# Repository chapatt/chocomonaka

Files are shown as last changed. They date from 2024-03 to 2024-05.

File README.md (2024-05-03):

# choco monaka

Fighting game controller

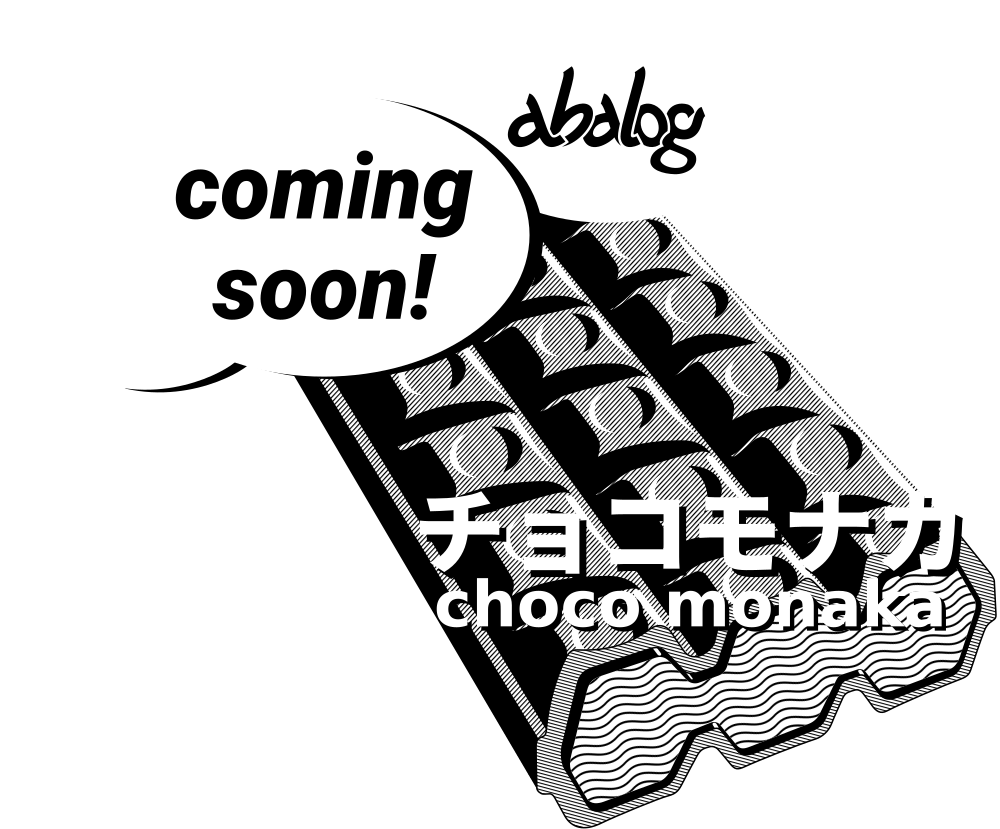
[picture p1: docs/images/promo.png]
abalog choco monaka promo


* [abalog.io](https://abalog.io)
* integrated RP2040
* compatible with [GP2040-CE firmware](https://gp2040-ce.info/)
* 18 face buttons
* Kailh Choc hotswap switches (v1 and v2 compatible)
* USB-C
* two slider switches (for e.g. tournament lockout, SOCD)
* USB-A for auth passthrough
* 0.96-in. OLED
* 254 x 127 x 17mm

PCB artwork:
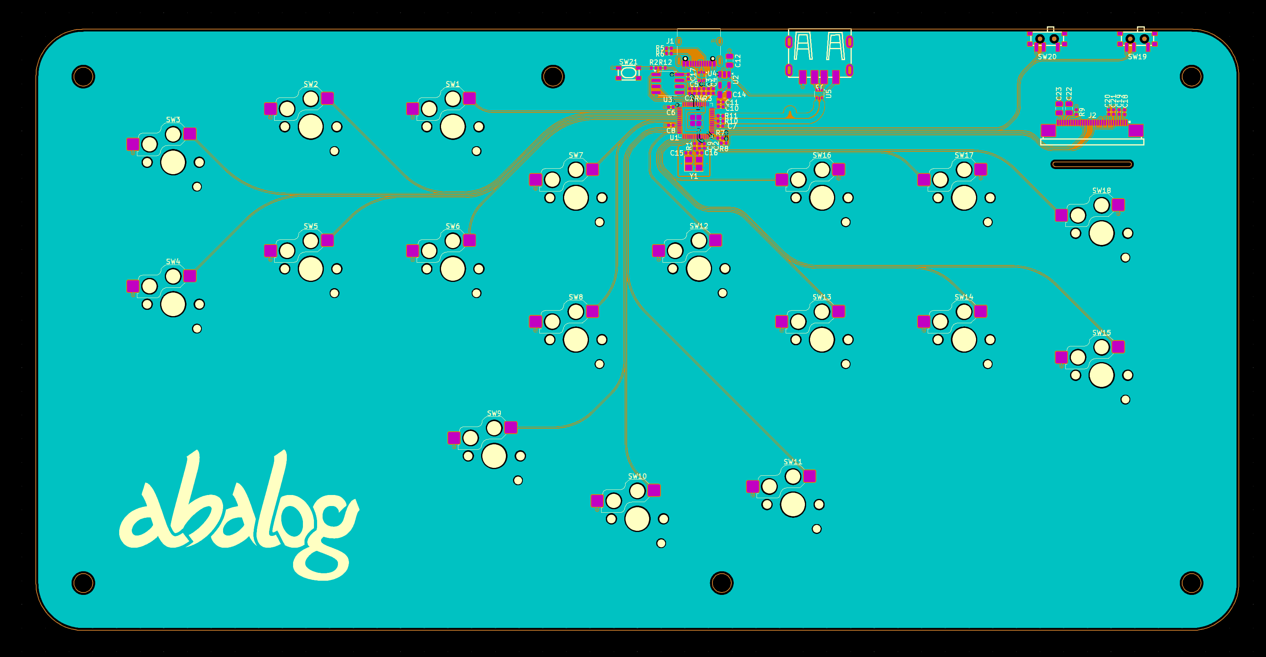
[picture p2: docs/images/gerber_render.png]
gerber render


v0.1.0 prototype front:
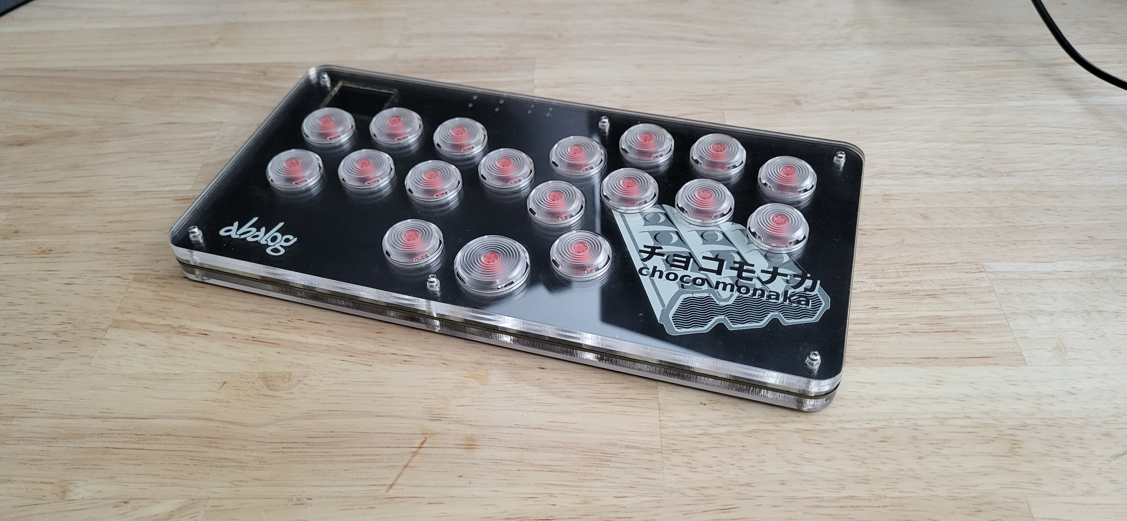
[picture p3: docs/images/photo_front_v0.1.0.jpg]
photo front


v0.1.0 prototype back:
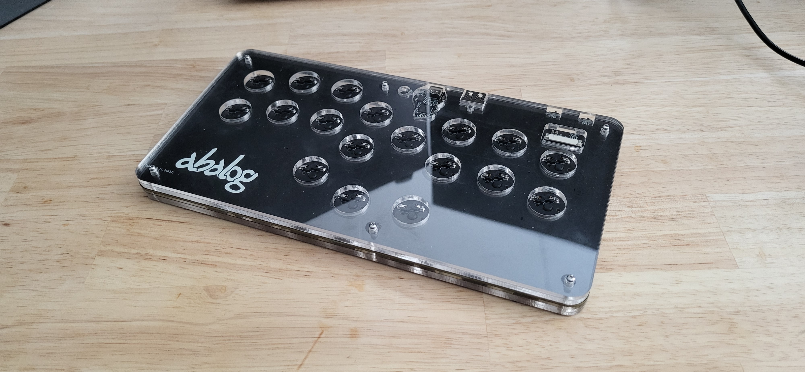
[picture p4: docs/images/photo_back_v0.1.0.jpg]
photo back


v0.1.0 prototype edge:
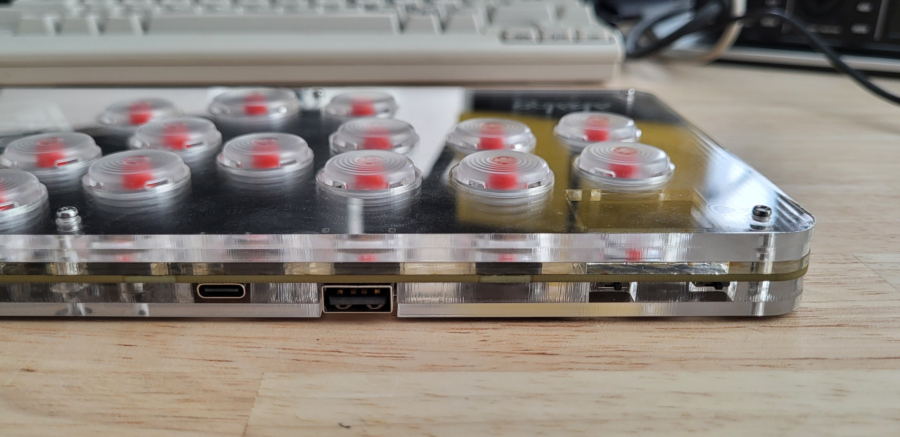
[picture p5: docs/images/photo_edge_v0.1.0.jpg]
photo edge


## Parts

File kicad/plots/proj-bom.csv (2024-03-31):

Comment | Designator | Footprint | LCSC
100n | C1,C2,C5,C6,C7,C8,C9,C10,C11 | Capacitor_SMD:C_0402_1005Metric | C1525
10u | C12,C14 | Capacitor_SMD:C_0805_2012Metric | C15850
15p | C15,C16 | Capacitor_SMD:C_0402_1005Metric | C1548
4.7u | C22 | Capacitor_SMD:C_0805_2012Metric | C1779
2.2u | C23 | Capacitor_SMD:C_0805_2012Metric | C377773
1u | C3,C4,C17,C18,C19,C20,C21 | Capacitor_SMD:C_0402_1005Metric | C52923
USB-C | J1 | proj:USB_C_Receptacle_XKB_U262-16XN-4BVC11 | C319148
OLED | J2 | proj:FPC-SMD_30P-P0.50_HDGC_0.5K-BS-30PWB | C2915410
USB-A | J3 | proj:USB-A-SMD_USB-M-21 | C42559
1k | R1,R2 | Resistor_SMD:R_0402_1005Metric | C11702
10k | R12 | Resistor_SMD:R_0402_1005Metric | C25744
22 | R3,R4,R10,R11 | Resistor_SMD:R_0402_1005Metric | C25092
5.1k | R5,R6 | Resistor_SMD:R_0402_1005Metric | C25905
4.7k | R7,R8 | Resistor_SMD:R_0402_1005Metric | C25900
330k | R9 | Resistor_SMD:R_0402_1005Metric | C25104
SW_DIP_x01 | SW1,SW2,SW3,SW4,SW5,SW6,SW7,SW8,SW9,SW10,SW11,SW12,SW13,SW14,SW15,SW16,SW17,SW18 | proj:SW_Hotswap_Kailh_Choc_V1V2 | C5333465
SW_SPDT | SW19,SW20 | proj:SW-SMD_SS-1290 | C589295
SW_Push | SW21 | proj:KEY-SMD_4P-L4.2-W3.2-P2.20-LS4.6 | C470427
RP2040 | U1 | proj:RP2040-QFN-56 | C2040
AP2112K-3.3 | U2 | Package_TO_SOT_SMD:SOT-23-5 | C51118
W25Q16JVSNIQ | U3 | Package_SO:SOIC-8_3.9x4.9mm_P1.27mm | C2456211
USBLC6-2P6 | U4,U5 | Package_TO_SOT_SMD:SOT-666 | C15999
X322512MOB4SI | Y1 | Crystal:Crystal_SMD_3225-4Pin_3.2x2.5mm | C70565

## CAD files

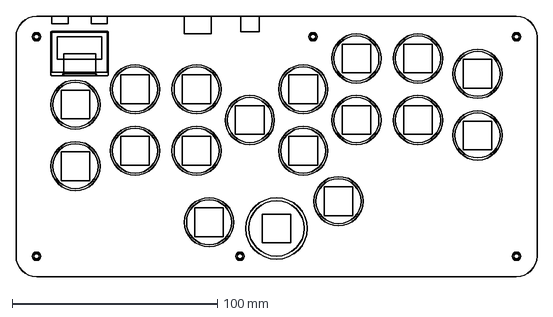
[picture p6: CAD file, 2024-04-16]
acrylic/layout-Sketch.dxf
254.0 x 127.0 mm

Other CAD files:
acrylic/layout.FCStd

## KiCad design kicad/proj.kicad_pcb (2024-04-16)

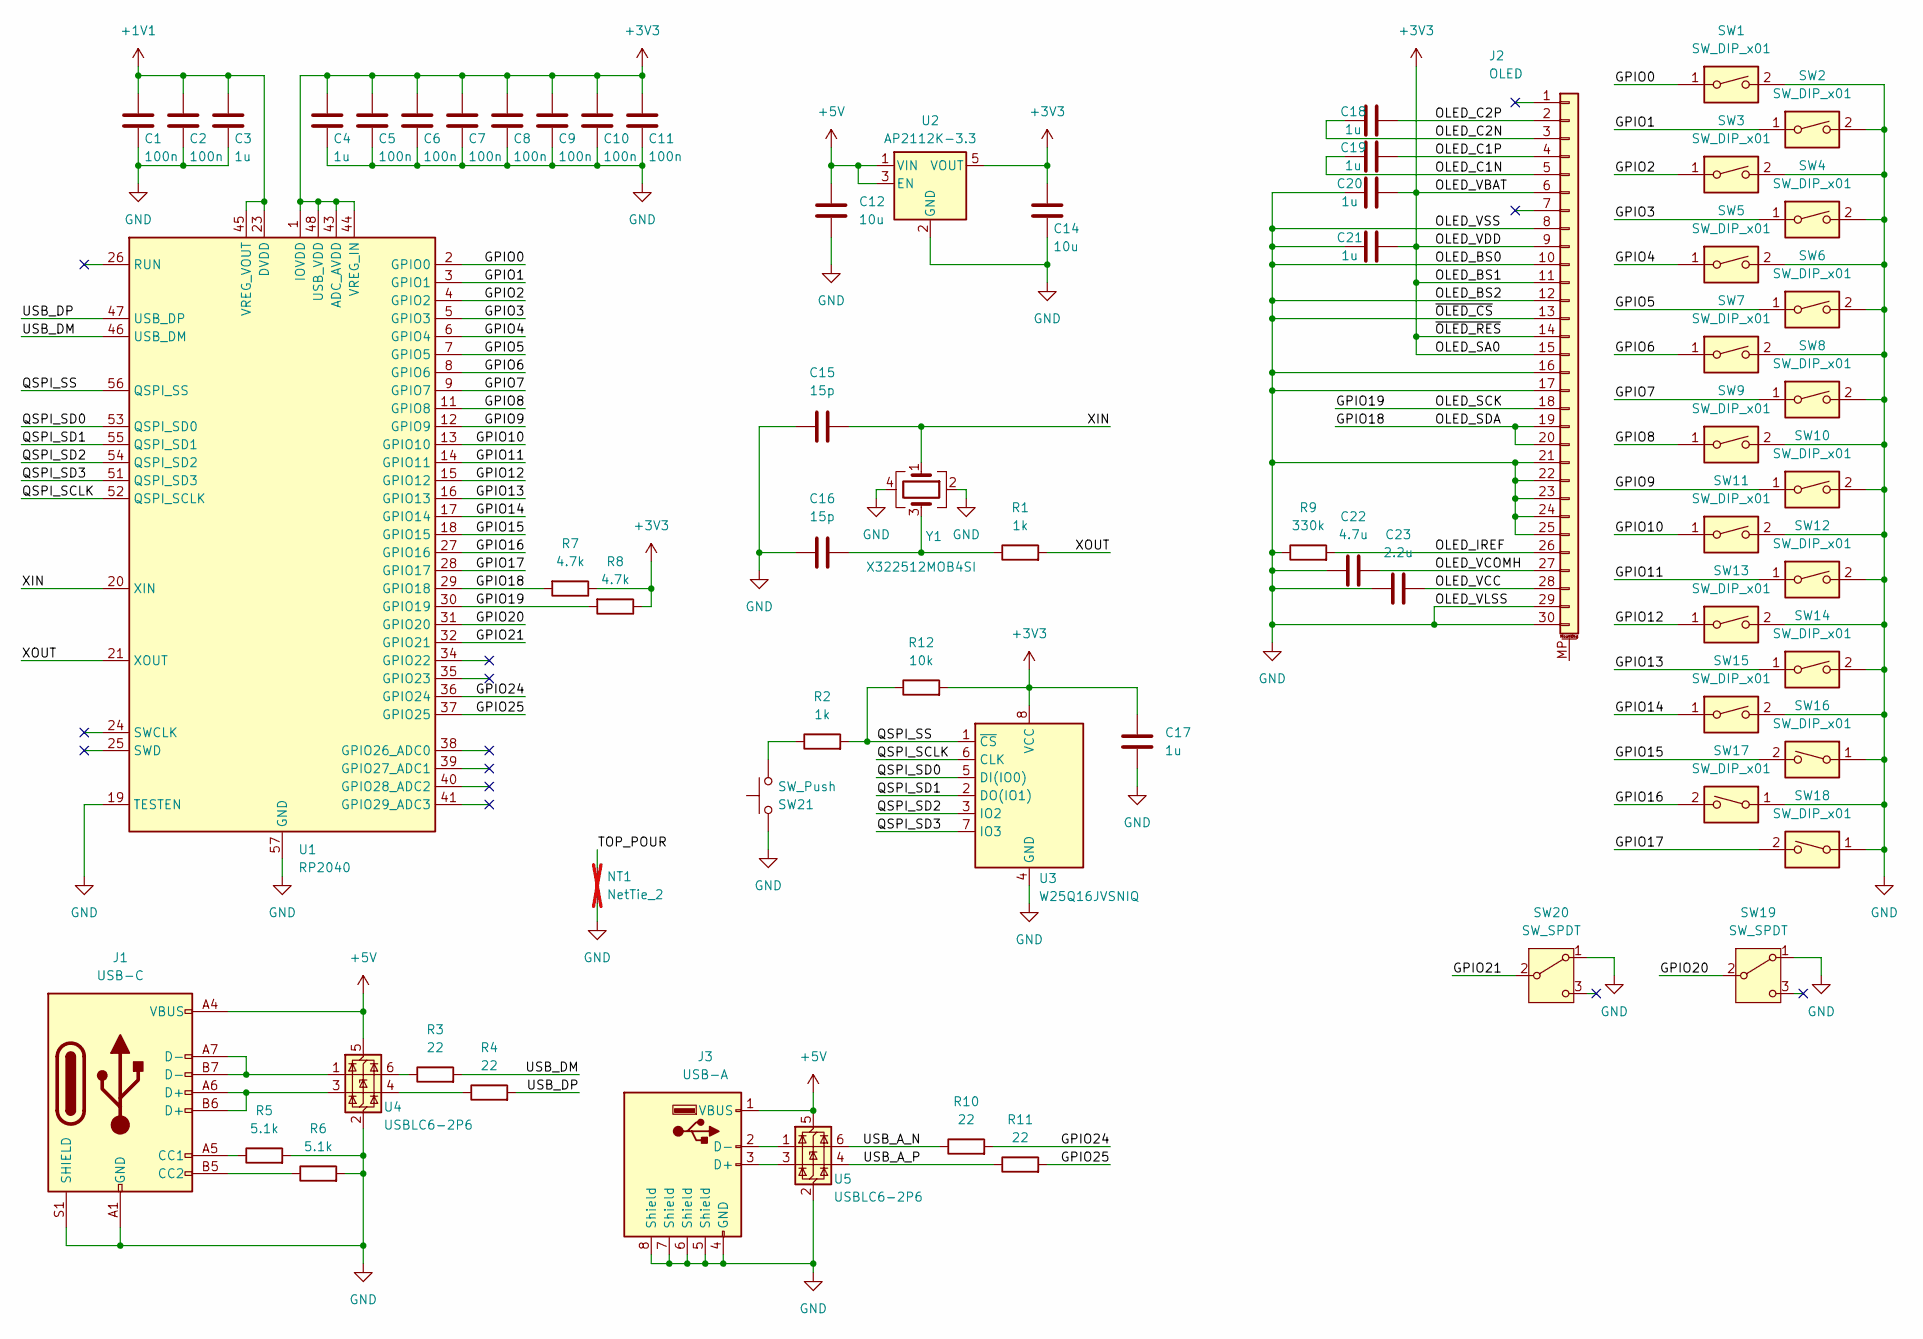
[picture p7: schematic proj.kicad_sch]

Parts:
C1, C2, C5, C6, C7, C8, C9, C10, C11: 100n; C_0402_1005Metric; LCSC C1525
C3, C4, C17, C18, C19, C20, C21: 1u; C_0402_1005Metric; LCSC C52923
C12, C14: 10u; C_0805_2012Metric; LCSC C15850
C15, C16: 15p; C_0402_1005Metric; LCSC C1548
C22: 4.7u; C_0805_2012Metric; LCSC C1779
C23: 2.2u; C_0805_2012Metric; LCSC C377773
J1: USB-C; USB_C_Receptacle_XKB_U262-16XN-4BVC11; LCSC C319148
J2: OLED; FPC-SMD_30P-P0.50_HDGC_0.5K-BS-30PWB; LCSC C2915410
J3: USB-A; USB-A-SMD_USB-M-21; LCSC C6331170
NT1: NetTie_2; NetTie-2_SMD_Pad0.5mm; not fitted
R1, R2: 1k; R_0402_1005Metric; LCSC C11702
R3, R4, R10, R11: 22; R_0402_1005Metric; LCSC C25092
R5, R6: 5.1k; R_0402_1005Metric; LCSC C25905
R7, R8: 4.7k; R_0402_1005Metric; LCSC C25900
R9: 330k; R_0402_1005Metric; LCSC C25104
R12: 10k; R_0402_1005Metric; LCSC C25744
SW1, SW2, SW3, SW4, SW5, SW6, SW7, SW8, SW9, SW10, SW11, SW12, SW13, SW14, SW15, SW16, SW17, SW18: SW_DIP_x01; SW_Hotswap_Kailh_Choc_V1V2; LCSC C5333465
SW19, SW20: SW_SPDT; SW-SMD_SS-1290; LCSC C589295
SW21: SW_Push; KEY-SMD_4P-L4.2-W3.2-P2.20-LS4.6; LCSC C470427
U1: RP2040; RP2040-QFN-56; LCSC C2040
U2: AP2112K-3.3; SOT-23-5; LCSC C51118
U3: W25Q16JVSNIQ; SOIC-8_3.9x4.9mm_P1.27mm; LCSC C2456211
U4, U5: USBLC6-2P6; SOT-666; LCSC C15999
Y1: X322512MOB4SI; Crystal_SMD_3225-4Pin_3.2x2.5mm; LCSC C70565

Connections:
+1V1: C1.1, C2.1, C3.1, U1.23 (DVDD), U1.45 (VREG_VOUT), U1.50 (DVDD)
+3V3: C4.1, C5.1, C6.1, C7.1, C8.1, C9.1, C10.1, C11.1, C14.1, C17.2, C20.2, C21.2, J2.6, J2.9, J2.11, J2.14, J2.15, R7.1, R8.1, R12.2, U1.1 (IOVDD), U1.10 (IOVDD), U1.22 (IOVDD), U1.33 (IOVDD), U1.42 (IOVDD), U1.43 (ADC_AVDD), U1.44 (VREG_IN), U1.48 (USB_VDD), U1.49 (IOVDD), U2.5 (VOUT), U3.8 (VCC)
+5V: C12.1, J1.A4 (VBUS), J1.A9 (VBUS), J1.B4 (VBUS), J1.B9 (VBUS), J3.1 (VBUS), U2.1 (VIN), U2.3 (EN), U4.5 (VBUS), U5.5 (VBUS)
/GPIO0: SW1.1, U1.2 (GPIO0)
/GPIO1: SW2.1, U1.3 (GPIO1)
/GPIO2: SW3.1, U1.4 (GPIO2)
/GPIO3: SW4.1, U1.5 (GPIO3)
/GPIO4: SW5.1, U1.6 (GPIO4)
/GPIO5: SW6.1, U1.7 (GPIO5)
/GPIO6: SW7.1, U1.8 (GPIO6)
/GPIO7: SW8.1, U1.9 (GPIO7)
/GPIO8: SW9.1, U1.11 (GPIO8)
/GPIO9: SW10.1, U1.12 (GPIO9)
/GPIO10: SW11.1, U1.13 (GPIO10)
/GPIO11: SW12.1, U1.14 (GPIO11)
/GPIO12: SW13.1, U1.15 (GPIO12)
/GPIO13: SW14.1, U1.16 (GPIO13)
/GPIO14: SW15.1, U1.17 (GPIO14)
/GPIO15: SW16.2, U1.18 (GPIO15)
/GPIO16: SW17.2, U1.27 (GPIO16)
/GPIO17: SW18.2, U1.28 (GPIO17)
/GPIO18: J2.19, J2.20, R7.2, U1.29 (GPIO18)
/GPIO19: J2.18, R8.2, U1.30 (GPIO19)
/GPIO20: SW19.2 (B), U1.31 (GPIO20)
/GPIO21: SW20.2 (B), U1.32 (GPIO21)
/GPIO24: R10.2, U1.36 (GPIO24)
/GPIO25: R11.2, U1.37 (GPIO25)
/OLED_C1N: C19.1, J2.5
/OLED_C1P: C19.2, J2.4
/OLED_C2N: C18.1, J2.3
/OLED_C2P: C18.2, J2.2
/OLED_IREF: J2.26, R9.2
/OLED_VCC: C23.2, J2.28
/OLED_VCOMH: C22.2, J2.27
/QSPI_SCLK: U1.52 (QSPI_SCLK), U3.6 (CLK)
/QSPI_SD0: U1.53 (QSPI_SD0), U3.5 (DI(IO0))
/QSPI_SD1: U1.55 (QSPI_SD1), U3.2 (DO(IO1))
/QSPI_SD2: U1.54 (QSPI_SD2), U3.3 (IO2)
/QSPI_SD3: U1.51 (QSPI_SD3), U3.7 (IO3)
/QSPI_SS: R2.2, R12.1, U1.56 (QSPI_SS), U3.1 (~CS)
/TOP_POUR: NT1.2
/USB_A_N: R10.1, U5.6 (I/O1)
/USB_A_P: R11.1, U5.4 (I/O2)
/USB_DM: R3.2, U1.46 (USB_DM)
/USB_DP: R4.2, U1.47 (USB_DP)
/XIN: C15.2, U1.20 (XIN), Y1.1
/XOUT: R1.2, U1.21 (XOUT)
GND: C1.2, C2.2, C3.2, C4.2, C5.2, C6.2, C7.2, C8.2, C9.2, C10.2, C11.2, C12.2, C14.2, C15.1, C16.1, C17.1, C20.1, C21.1, C22.1, C23.1, J1.A1 (GND), J1.A12 (GND), J1.B1 (GND), J1.B12 (GND), J1.S1 (SHIELD), J2.8, J2.10, J2.12, J2.13, J2.16, J2.17, J2.21, J2.22, J2.23, J2.24, J2.25, J2.29, J2.30, J3.4 (GND), J3.5 (Shield), J3.6 (Shield), J3.7 (Shield), J3.8 (Shield), NT1.1, R5.2, R6.2, R9.1, SW1.2, SW2.2, SW3.2, SW4.2, SW5.2, SW6.2, SW7.2, SW8.2, SW9.2, SW10.2, SW11.2, SW12.2, SW13.2, SW14.2, SW15.2, SW16.1, SW17.1, SW18.1, SW19.1 (A), SW20.1 (A), SW21.2, U1.19 (TESTEN), U1.57 (GND), U2.2 (GND), U3.4 (GND), U4.2 (GND), U5.2 (GND), Y1.2, Y1.4
unnamed: C16.2, R1.1, Y1.3
unnamed: J1.A5 (CC1), R5.1
unnamed: J1.B5 (CC2), R6.1
unnamed: J1.A6 (D+), J1.B6 (D+), U4.3 (I/O2)
unnamed: J1.A7 (D-), J1.B7 (D-), U4.1 (I/O1)
unnamed: J3.3 (D+), U5.3 (I/O2)
unnamed: J3.2 (D-), U5.1 (I/O1)
unnamed: R2.1, SW21.1
unnamed: R3.1, U4.6 (I/O1)
unnamed: R4.1, U4.4 (I/O2)

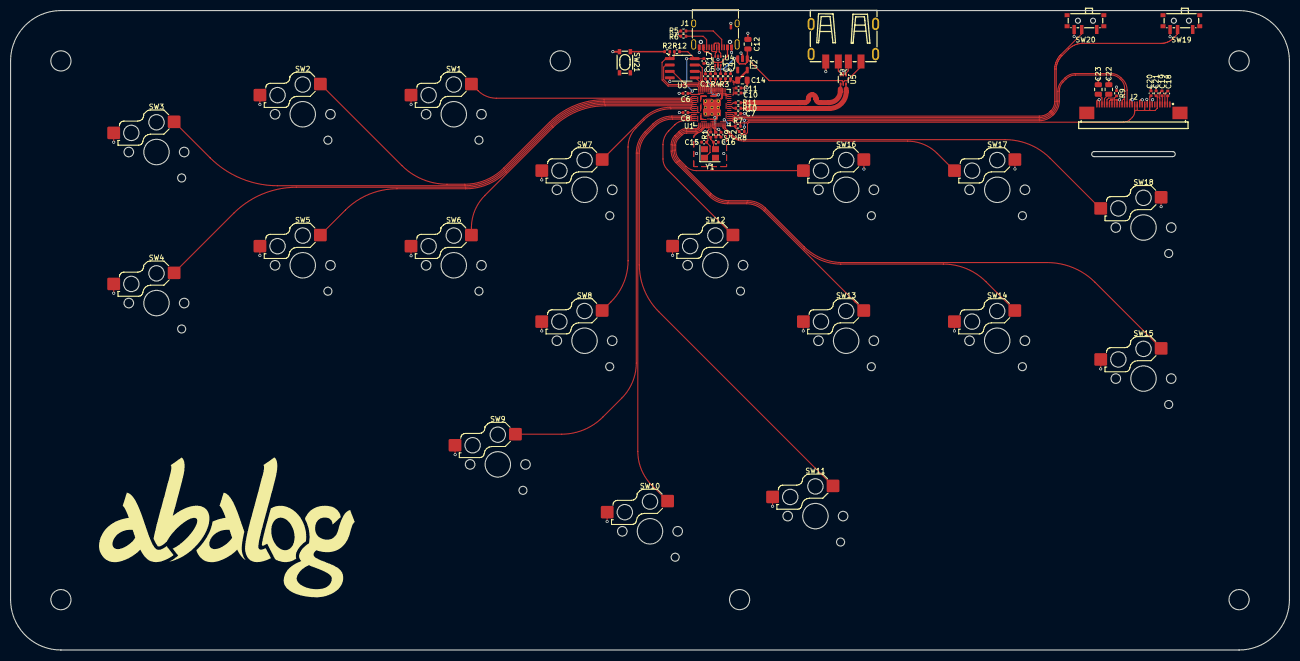
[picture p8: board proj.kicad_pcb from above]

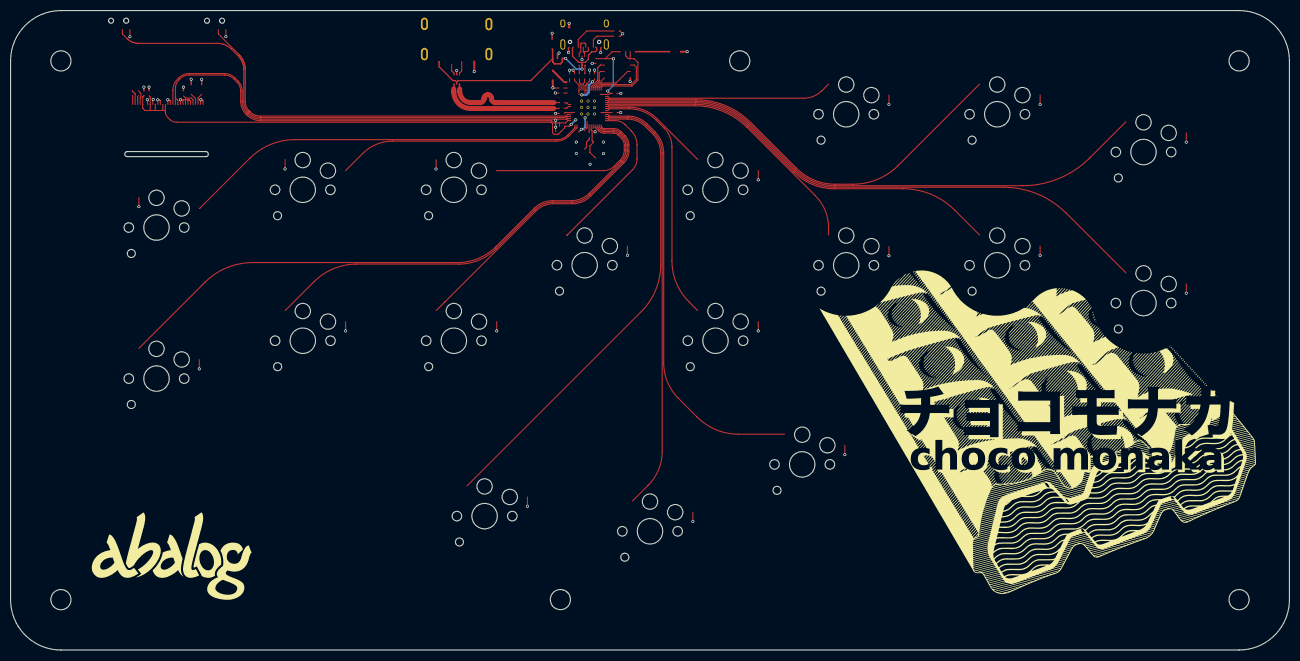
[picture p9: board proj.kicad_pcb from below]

Board: 2 copper layers, 254.0 x 127.0 mm, 65 parts (18 on the bottom side), 57 nets.

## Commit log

2024-03-29 fillet trace corners
    [proj.kicad_pcb]
2024-03-29 remove unnecessary xtal guard ring keepout
    [proj.kicad_pcb]
2024-03-30 add artwork to board
    [layout.FCStd, proj.kicad_pcb]
2024-03-30 adapt for LCSC part numbers
    [proj.kicad_pcb, proj.kicad_sch]
2024-03-31 remove redundant 3dmodels dir
    [u262-161n-4bvc11.stp]
2024-03-31 replace USB-A with top mount part
    [proj.kicad_pcb, proj.kicad_sch]
2024-03-31 add fabrication outputs
    [proj-B_Cu.gbl, proj-B_Mask.gbs, proj-B_Paste.gbp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]
2024-04-01 add 3d renders of board
2024-04-15 add initial laser cut files
2024-04-16 add acrylic layouts
    [layout-Sketch.dxf, layout.FCStd, layout.dxf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]
